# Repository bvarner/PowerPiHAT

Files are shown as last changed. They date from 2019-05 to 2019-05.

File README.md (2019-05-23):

# PowerPiHAT
A Raspberry Pi HAT for building a whole-house electricity monitor using PZCT-02 split core current transformers.

## Design Decisions
* Use an inexpensive split-core CT capable of 100A, that can be clipped onto the mains in my electrical panel.
* Allow for easy connection of the CTs to the device.
* Produce a spec-compliant HAT.
    * Safely back-power the Raspberry Pi from the HAT.
    * Proper cutouts, clearances, etc.
* Use an inexpensive ADS1115 module to reduce overall part cost. (It's cheaper to buy a breakout module than it is to buy the chips in low quantity)
    * GY-ADS1115 (Available from ebay, aliexpress, etc.)
    * Adafruit ADS1115. Both are pin-compatible, and there are mount holes for each module on the board.

## The Board
You can manufacture the board at home, using dual-sided 2-oz copper-clad board. Important: The traces for the analog input are sized assuming 2oz copper.

I've optimized trace spacing for what I've been capable of producing at home using the 'laser-printer hot-transfer' method to mask prior to chemical etching.
There are also extraneous vias to breakout header pins in case soldering both sides of the pin is problematic (no through-hole plating).

The footprints of the SMT components could be smaller for mass production, but I chose the sizes based on what I've been able to hand-solder with an inexpensive 'hobbiest' 25watt soldering iron with a blade tip.

Contrary to the HAT spec, the mounting holes are not defined as non-plated through-hole in the current repository. Since I'm hand-manufacturing these boards, I need to have a precise drill location. KiCad doesn't seem to emit drill markers to the etch layers unless the hole is plated through-hole. So, I've set those as plated, and will drill the entire pad away.

## Sourcing Parts

Estimated total cost fo the build, with more parts than you need (volume pricing on imports), comes to around **$65** -- including the RaspberryPi!

### Import Parts / Supplies for the PCB

| Quantity | Part | Est. Cost Each | Est. Build Cost |
| --- | ---- | ---:| ---:|
| 4 | [PZCT-02 CT](https://www.aliexpress.com/wholesale?SearchText=PZCT-02) | ~$3.75 | $16 |
| 1 | [GY-ADS1115](https://www.aliexpress.com/wholesale?SearchText=ADS1115) | ~$1.60 | $2 |
| 1 | [Double Sided Copper Clad Board](https://www.aliexpress.com/wholesale?SearchText=double+side+copper+clad) | ~$0.60 | ? |
| 1 | [Raspberry Pi Model 3 A+](https://www.adafruit.com/product/4027) | ~$25 | $32 | 
| 1 | [DC-092 Barrel Jack](https://www.aliexpress.com/item/Free-shipping-20pcs-lot-DC-connector-tablet-female-DC-power-jack-SMD-DIP-PCB-mounting-DC/32684566314.html) | ~$0.16 | $2 |
| 4 | [3.5mm Mono Audio Jacks - SMT](https://www.aliexpress.com/item/Promotion-5-Pcs-5-Pin-3-5mm-Audio-Mono-Jack-Socket-PCB-Panel-Mount-for-Headphone/32622989834.html) | ~$0.15 | $1 |
| 4 | [3.5mm Mono Audio Plugs](https://www.aliexpress.com/item/10Pcs-3-5MM-Headphone-Plug-2-Pole-Mono-Audio-Video-Welding-Line-For-Headphone-Socket/32789017811.html) | ~$0.11 | $1 |

### DigiKey BOM
As of 5/21/2019, the estimated BOM cost is ~$10.

```
"Manufacturer Part Number"	"Digi-Key Part Number"	"Customer Reference"	"Reference Designator"	"Quantity"	"Unit Price"	"Description"
"DMG2305UX-13"	"DMG2305UX-13DICT-ND"	""	"Q1"	"1"	"0.45000"	"MOSFET P-CH 20V 4.2A SOT23"
"DMMT5401-7-F"	"DMMT5401-FDICT-ND"	""	"Q2"	"1"	"0.45000"	"TRANS 2PNP 150V 0.2A SOT26"
"RNCF0805DTE10K0"	"RNCF0805DTE10K0CT-ND"	""	""	"10"	"0.14000"	"RES 10K OHM 0.5% 1/8W 0805"
"RNCF0805DTE47K0"	"RNCF0805DTE47K0CT-ND"	""	"R24"	"1"	"0.15000"	"RES 47K OHM 0.5% 1/8W 0805"
"CAT24C32WI-GT3"	"CAT24C32WI-GT3CT-ND"	""	"U2"	"1"	"0.20000"	"IC EEPROM 32K I2C 1MHZ 8SOIC"
"RNCF0805DTE3K90"	"RNCF0805DTE3K90CT-ND"	""	""	"2"	"0.15000"	"RES 3.9K OHM 0.5% 1/8W 0805"
"CRGP2010F18R"	"A130639CT-ND"	""	""	"4"	"0.43000"	"CRGP 2010 18R 1%"
"CL21A106KPFNNNE"	"1276-1052-1-ND"	""	""	"4"	"0.13000"	"CAP CER 10UF 10V X5R 0805"
"SSQ-110-03-T-S"	"SAM1206-10-ND"	""	"J1"	"1"	"1.20000"	"CONN RCPT 10POS 0.1 TIN PCB"
"SSW-120-01-T-D"	"SAM1212-20-ND"	""	"J3"	"1"	"2.90000"	"CONN RCPT 40POS 0.1 TIN PCB"
```

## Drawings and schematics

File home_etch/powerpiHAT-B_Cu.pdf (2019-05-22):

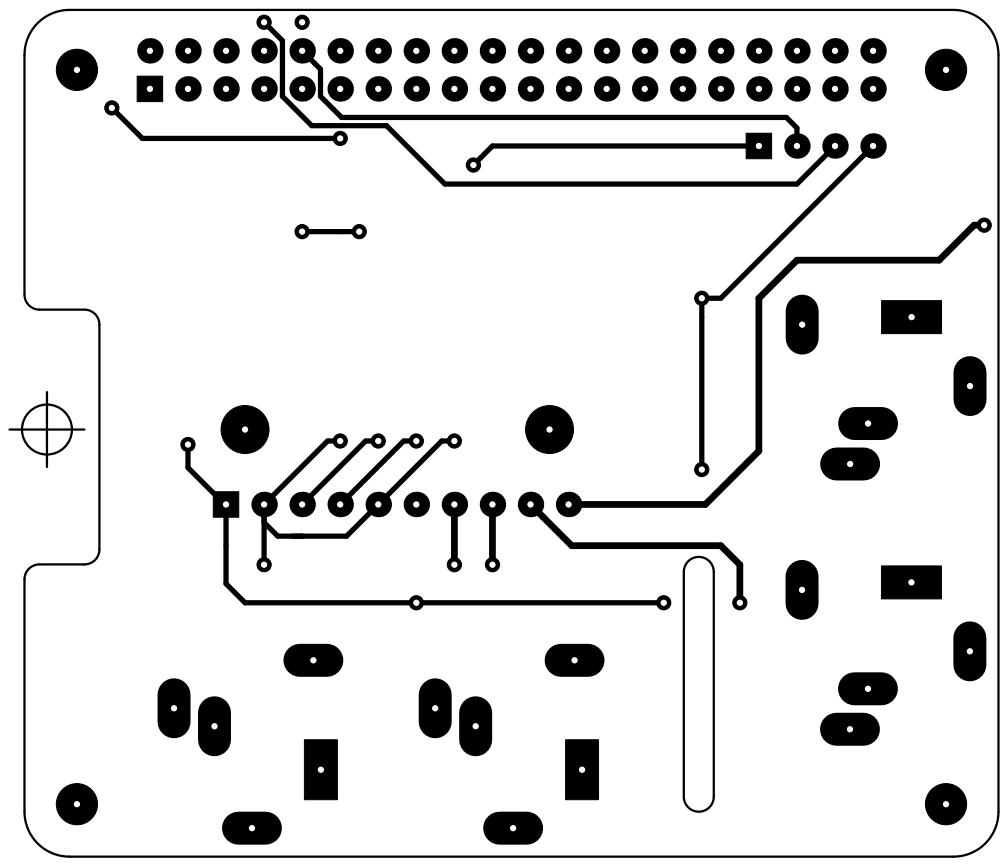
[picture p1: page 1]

File: powerpiHAT.kicad_pcb Sheet: Bryan Varner V 1.0.0

Id: 1/1 Title: Pi Power Monitor HAT

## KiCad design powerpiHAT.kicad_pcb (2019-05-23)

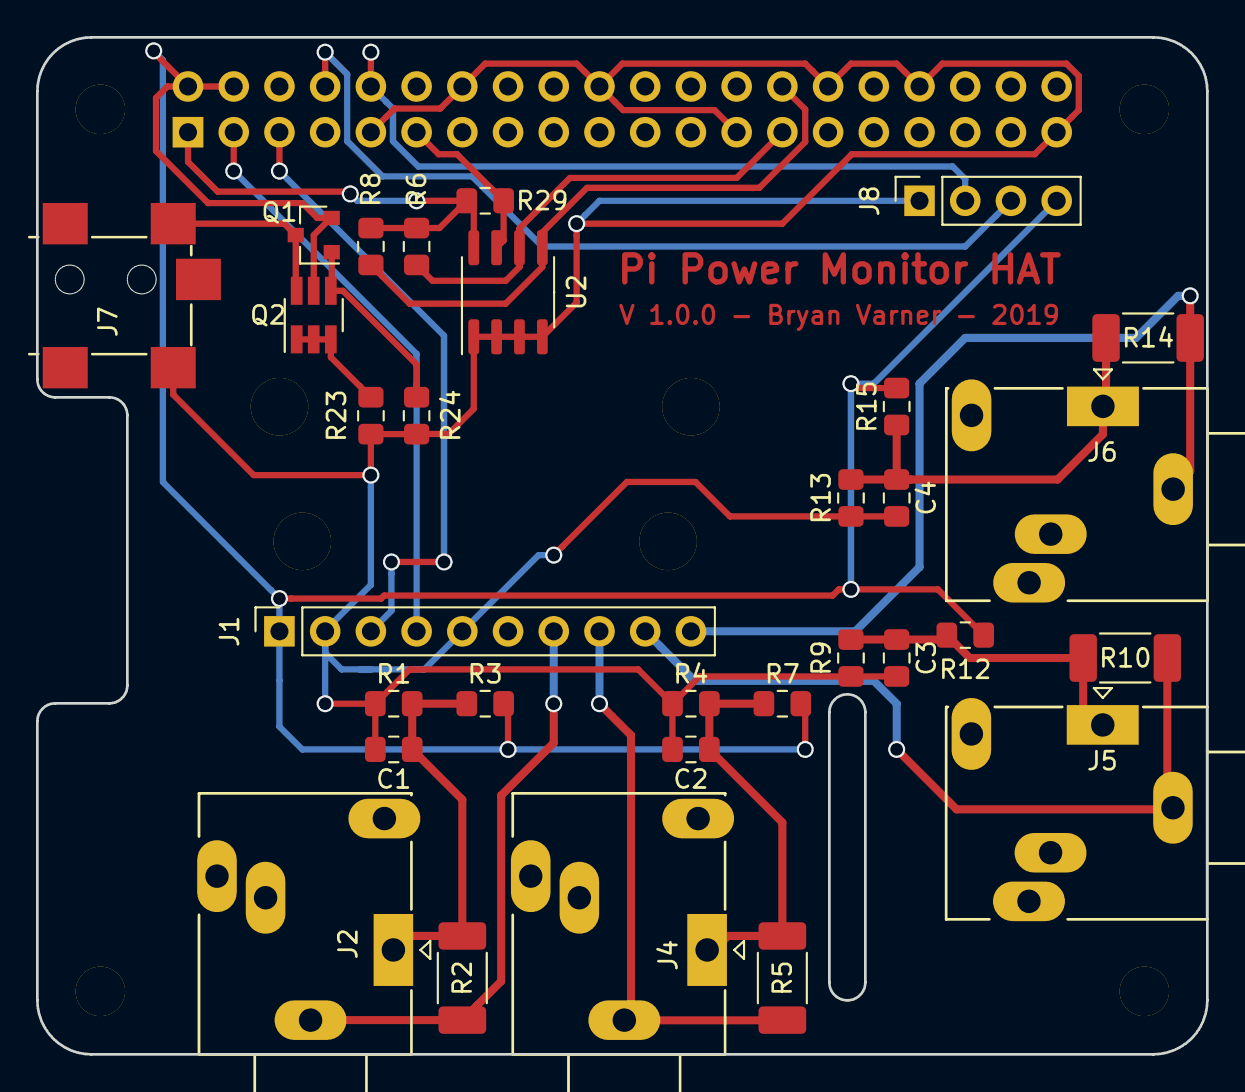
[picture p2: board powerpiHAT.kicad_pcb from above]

Board: 2 copper layers, 65.0 x 56.5 mm, 40 parts (1 on the bottom side), 21 nets.

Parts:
C1, C2, C3, C4: 10uF; C_0805_2012Metric_Pad1.15x1.40mm_HandSolder
H1, H2, H3, H4: 3mm_Mounting_Hole; MountingHole_2.7mm_M2.5
H5, H6, H7, H8: 3mm_Mounting_Hole; MountingHole_3.2mm_M3_DIN965
J1: Conn_01x10; PinSocket_1x10_P2.54mm_Vertical
J2, J4, J5, J6: AudioJack2_Dual_Ground_Switche; Jack_3.5mm_Ledino_KB3SPRS_Horizontal
J3: 40HAT; PinSocket_2x20_P2.54mm_Vertical
J7: Barrel_Jack; BarrellJack-DC-902_SMT_Horizontal
J8: Conn_01x04; PinSocket_1x04_P2.54mm_Vertical
Q1: DMG2305UX; SOT-23
Q2: DMMT5401; SOT-23-6_Handsoldering
R1, R3, R4, R7, R9, R12, R13, R15, R23, R29: 10K; R_0805_2012Metric_Pad1.15x1.40mm_HandSolder
R2, R5, R10, R14: 18; R_2010_5025Metric_Pad1.52x2.65mm_HandSolder
R6, R8: 3.9K; R_0805_2012Metric_Pad1.15x1.40mm_HandSolder
R24: 47K; R_0805_2012Metric_Pad1.15x1.40mm_HandSolder
U2: CAT24C32; SOIC-8_3.9x4.9mm_P1.27mm

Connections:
/ADS_A0: J1.7, J2.S, R2.1
/ADS_A1: J1.8, J4.S, R5.1
/ADS_A2: J1.9, J5.S, R10.1
/ADS_A3: J1.10, J6.S, R14.1
/BCM_2: J1.4, J3.3
/BCM_3: J1.3, J3.5
/ID_SC_EEPROM: J3.28, R8.2, U2.5
/ID_SD_EEPROM: J3.27, R6.2, U2.6
/P3V3_HAT: J3.1, R6.1, R8.1, R29.1, U2.8
/P5V: J7.1, Q1.3, Q2.6
/P5V_HAT: J1.1, J3.2, J3.4, J8.4, Q1.2, Q2.5, R3.2, R7.2, R12.2, R15.2
/PI_UART_RXD: J3.10, J8.2
/PI_UART_TXD: J3.8, J8.3
/WP_EEPROM: J3.11, R29.2, U2.7
GND: C1.2, C2.2, C3.2, C4.2, J1.2, J1.5, J3.9, J3.14, J3.20, J3.25, J3.30, J3.34, J3.39, J7.2, J8.1, R1.1, R4.1, R9.1, R13.1, R23.2, R24.2, U2.1, U2.2, U2.3, U2.4
unnamed: C1.1, J2.T, R1.2, R2.2, R3.1
unnamed: C2.1, J4.T, R4.2, R5.2, R7.1
unnamed: C3.1, J5.T, R9.2, R10.2, R12.1
unnamed: C4.1, J6.T, R13.2, R14.2, R15.1
unnamed: Q1.1, Q2.4, R24.1
unnamed: Q2.1, Q2.2, Q2.3, R23.1

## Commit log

2019-05-14 Initial checkin of the initial revision of hardware.
    [powerpiHAT.kicad_pcb, powerpiHAT.sch]
2019-05-21 Essentially, release 1.0.0 of the PowerPiHAT... we'll see if there's electrical changes necessary once we get a couple boards etched and populated.
    [powerpiHAT.kicad_pcb, powerpiHAT.sch]
2019-05-21 Include the UART on a breakout header, for additional bits later.
    [powerpiHAT.kicad_pcb, powerpiHAT.sch]
2019-05-22 Breakout Header for 5v, Gnd, UART
    [powerpiHAT.kicad_pcb, powerpiHAT.sch]
2019-05-22 Board Margin.
    [powerpiHAT.kicad_pcb]
2019-05-22 Mounting holes are now through-hole, so we get reference points for drilling (drill marks) by hand.
    [powerpiHAT.kicad_pcb]
2019-05-23 Moved the I2C For the ADS to the proper lines.
    [powerpiHAT.kicad_pcb, powerpiHAT.sch]
2019-05-23 Mount positions for the adafruit module. I happen to have both types on-hand for testing.d
    [powerpiHAT.kicad_pcb, powerpiHAT.sch]
